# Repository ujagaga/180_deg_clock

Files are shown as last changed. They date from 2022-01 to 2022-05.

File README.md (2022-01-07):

# ESP8266 Semi-mechanical Clock

This is a wall clock based on ESP8266. It uses a 12V power supply. 
The time is synchronized from local network. Hours and minutes are displayed using servo motors that rotate only 180 degrees.

## Implementation  Details

The hour hand is moved by the servo motor using two gears so that the hand can be supported by a 3D printed bearing and relieve some weight from the motor. You can either use same sized gears for 180 degree movement or make a custom ratio like 1:2 to achieve 360 degrees as is here.
For hour numbers, you can use anything you like, custom printed shapes, familly photos, wall art, light bulbs,...
There is also a pendulum for purely aesthetic reasons. It uses two coils and a neodimium magnet to run. It can be controlled by the ESP8266, so it can automatically run when powered on, or it can be standalone, but then you have to manually swing it once to get it started.

## Local time server

Using internet NTP server is accurate, but only shows UTC time. Adjusting for daylight savings can be tricky in an embedded device like ESP8266, so I wrote a simple python script to broadcast local time on a custom UDP port. It can be deployed on any computer on local network, so the clock can synchronize when ever this computer is online. The server broadcasts the number of seconds passed in the current day, so you only need to run it one per day.
It's only dependency is Python3.

## Status

Not yet ready, but soon... If you wish to be notified when it is ready, let me know.

## Contact

email: ujagaga@gmail.com

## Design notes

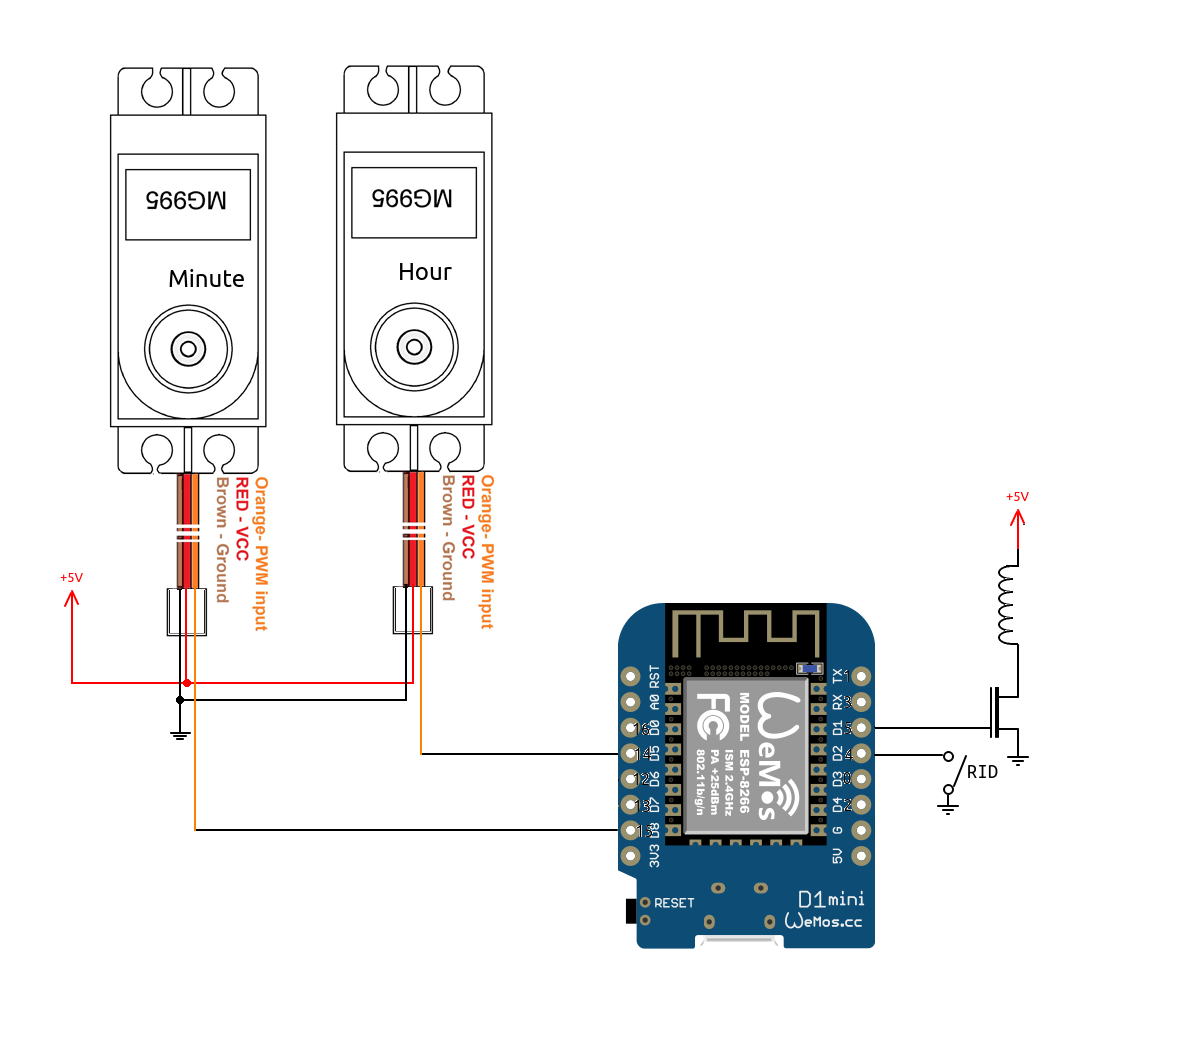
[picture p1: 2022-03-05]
Schematic/D1_mini.png

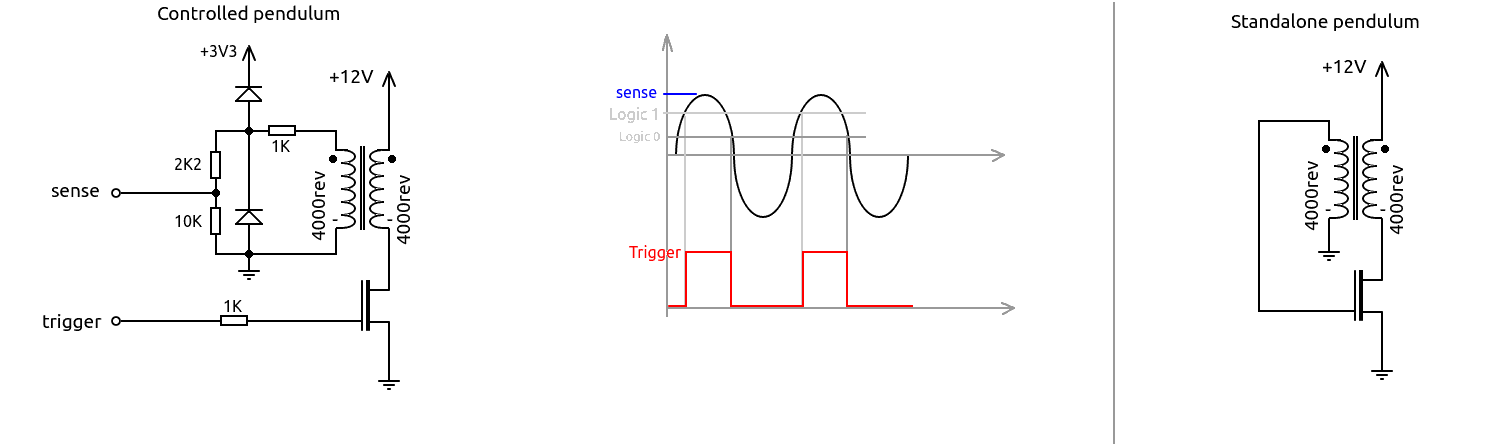
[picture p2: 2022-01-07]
Schematic/Pendulum_schematic.png

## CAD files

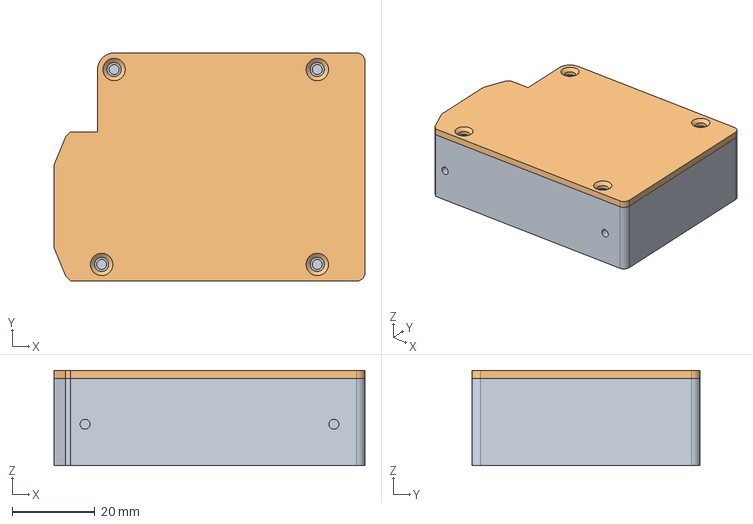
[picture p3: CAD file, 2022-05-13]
3DModel/MagnetSpool.FCStd
75.0 x 55.0 x 23.0 mm
Cover

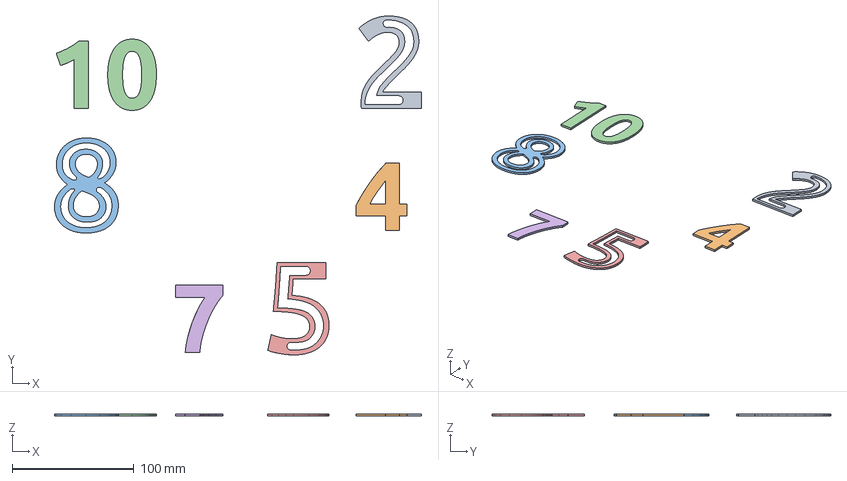
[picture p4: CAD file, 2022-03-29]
3DModel/Numbers.FCStd
301.1 x 278.0 x 2.00 mm
Big_2
Small_4
Big_8
Small_10
Big_5
Small_7

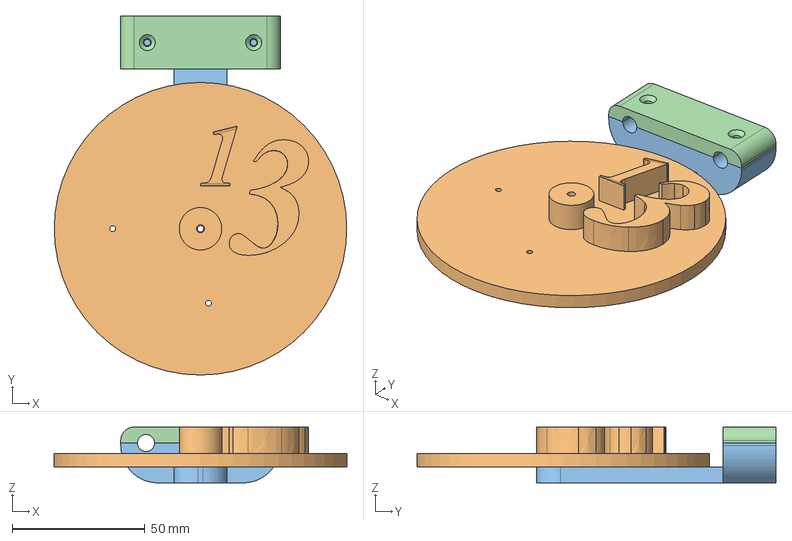
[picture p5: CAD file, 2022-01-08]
3DModel/Logo.FCStd
110.0 x 135.0 x 21.0 mm
RR_Logo_base
PendulumBarsHoder
PendulumBarsFastner

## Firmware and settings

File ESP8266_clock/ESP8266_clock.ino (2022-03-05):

#include <ESP8266WiFi.h>
#include <ESP8266WiFiMulti.h>
#include <Servo.h>
#include "udp_sync_client.h"
#include "servo_hand.h"
#include "config.h"
#include "pendulum.h"
#include "ota.h"

ESP8266WiFiMulti WiFiMulti;

void setup()
{
  Serial.begin(115200);
  pinMode(LED_PIN, OUTPUT);
  digitalWrite(LED_PIN, HIGH);
   
  WiFi.mode(WIFI_STA);
  WiFiMulti.addAP(SSID_1, PASS_1);
  WiFiMulti.addAP(SSID_2, PASS_2);

  bool ledTgl = false;
  
  Serial.print( "\n\nConnecting" );
  while ( WiFiMulti.run() != WL_CONNECTED ) {
    delay ( 500 );
    ESP.wdtFeed();
    Serial.print ( "." );
    ledTgl = !ledTgl;
    if(ledTgl){
      digitalWrite(LED_PIN, HIGH);
    }else{
      digitalWrite(LED_PIN, LOW);
    }
  }
  String IP =  WiFi.localIP().toString();
  String wifi_statusMessage = "\nConnected to: " + WiFi.SSID() + String(". IP address: ") + IP;   
  Serial.println(wifi_statusMessage);  
  digitalWrite(LED_PIN, HIGH);

  UDPSYNC_init();
  SERVO_init();
  PENDULUM_init();
}

void loop() {  
  if(OTA_updateInProgress()){
    OTA_process();
  }else{
    UDPSYNC_process();
    PENDULUM_process();
    SERVO_process();
    PENDULUM_process();
  }
}

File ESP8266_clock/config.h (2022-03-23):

#ifndef CONFIG_H_
#define CONFIG_H_

#define HOUR_SERVO_PIN              (14) 
#define MINUTE_SERVO_PIN            (15)
#define PENDULUM_SENSE_PIN          (4)
#define PENDULUM_TRIGGER_PIN        (5)
#define LED_PIN                     (2)

#define SSID_1                      "OhanaCode"
#define PASS_1                      "0hana0ffice"

#define SSID_2                      "ujagaga"
#define PASS_2                      "ohana130315"

#define UDP_PORT                    (60000)
#define SYNC_TIMEOUT                (1000) 
#define MAX_SECONDS_PER_DAY         (86400ul)
#define SECONDS_PER_12_H            (MAX_SECONDS_PER_DAY / 2)
#define SECONDS_PER_MINUTE          (60)
#define MINUTES_PER_HOUR            (60)
#define SECONDS_PER_HOUR            (SECONDS_PER_MINUTE * MINUTES_PER_HOUR)

// For OTA update
#define DEVICE_NAME                 "OC_ESP_CLOCK"

// For debugging purposes.
//#define TEST_SWEEP

#endif

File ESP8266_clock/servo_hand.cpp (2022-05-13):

#include <Servo.h>
#include "servo_hand.h"
#include "udp_sync_client.h"
#include "config.h"

#define MOVE_TIMEOUT    (100)
#define H_SRV_MIN       (490)
#define H_SRV_MAX       (2460)


Servo hourServo;
Servo minuteServo;
static uint32_t servo_timestamp = 0;
static uint32_t move_timestamp = 0;
static int m_angle = 180;
static int h_angle = 0;
static int targetHourAngle = 0;
static int targetMinuteAngle = 0;

#ifdef DETACH_HOUR_SERVO
static bool hourServoAttached = false;
#endif

void SERVO_init(){
  pinMode(HOUR_SERVO_PIN, OUTPUT);
  pinMode(MINUTE_SERVO_PIN, OUTPUT);
  hourServo.attach(HOUR_SERVO_PIN, H_SRV_MIN, H_SRV_MAX);
  minuteServo.attach(MINUTE_SERVO_PIN, 500, 2500);
  minuteServo.write(m_angle);  

#ifdef DETACH_HOUR_SERVO
  hourServoAttached = true;
#endif
}

int calc_m_angle(int seconds){
  if(seconds >= SECONDS_PER_HOUR){
    seconds = SECONDS_PER_HOUR - 1;
  }else if(seconds < 0){
    seconds = 0;
  }

  int ratio = SECONDS_PER_HOUR / 180;
  int result = seconds / ratio;

  return (180 - result);
}

int calc_h_angle(int seconds){
  if(seconds >= SECONDS_PER_12_H){
    seconds = SECONDS_PER_12_H - 1;
  }else if(seconds < 0){
    seconds = 0;
  }

  int ratio = SECONDS_PER_12_H / 180;
  int result = seconds / ratio;

  float current = (float)result;
  if(result > 135){
    result = (int)(current * 1.01);
  }else if(result > 90){
    result = (int)(current * 1.01);
  }else if(result > 45){
    result = (int)(current * 0.98);
  }

  return result;
}

#ifdef TEST_SWEEP
  int angle = 1;
  int increment = 1;
#endif

void SERVO_process(){
#ifdef TEST_SWEEP
  if((millis() - servo_timestamp) > MOVE_TIMEOUT){
    servo_timestamp = millis();
    
    if((angle >= 180) || (angle <= 0)){      
      increment = -increment;
    }

    angle += increment;    
    hourServo.write(angle);    
  }
#else
  
  if((millis() - servo_timestamp) > SYNC_TIMEOUT){
    servo_timestamp = millis();

    int seconds = UDPSYNC_getCurrentSeconds();
    targetHourAngle = calc_h_angle(seconds);    

    int secondsInLastHour = seconds % SECONDS_PER_HOUR;
    targetMinuteAngle = calc_m_angle(secondsInLastHour);        

  }else if((millis() - move_timestamp) > MOVE_TIMEOUT){
    if(targetHourAngle > h_angle){
      h_angle++;
      
#ifdef DETACH_HOUR_SERVO
      if(!hourServoAttached){
        hourServo.attach(HOUR_SERVO_PIN, H_SRV_MIN, H_SRV_MAX);
        hourServoAttached = true;
      }
#endif      
    }else if(targetHourAngle < h_angle){
      h_angle--;
      
#ifdef DETACH_HOUR_SERVO
      if(!hourServoAttached){
        hourServo.attach(HOUR_SERVO_PIN, H_SRV_MIN, H_SRV_MAX);
        hourServoAttached = true;
      }
#endif      
    }else{
#ifdef DETACH_HOUR_SERVO
      if(hourServoAttached){
        hourServo.detach();
        hourServoAttached = false;
      }      
#endif 
    }

    if(targetMinuteAngle > m_angle){
      m_angle++;
    }else if(targetMinuteAngle < m_angle){
      m_angle--;
    }

    hourServo.write(h_angle);
    minuteServo.write(m_angle);    
      
    move_timestamp = millis();
  }

#endif // TEST_SWEEP
}

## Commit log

2022-01-05 Switched local time server to UDP broadcast
2022-01-06 Add 7 seg model
    [7_segment.FCStd]
2022-01-06 Updated 3D Models
    [7_segment.FCStd, ClockGears.FCStd]
2022-01-07 3D design first compleated version
    [ClockGears.FCStd, Logo.FCStd]
2022-01-07 Add schematic
2022-01-08 Adjusted schematic
2022-01-08 3D model updates
    [Logo.FCStd]
2022-03-05 Bad hour hand
    [7_segment.FCStd, MagnetSpool.FCStd]
2022-03-23 Updated the clock
    [Numbers.FCStd]
2022-03-23 Add comments
    [Numbers.FCStd]
2022-03-29 Add servo detach
    [Numbers.FCStd]
